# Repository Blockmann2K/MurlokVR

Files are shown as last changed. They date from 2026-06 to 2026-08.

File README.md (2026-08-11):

<div align="center">


# MurlokVR
A Stupid Simple Custom "DIY" VR Headset. Built With Rust 🦀 and C++ (OpenVR Driver) ⚙️

</div>

## Notice
If You Want To Clone This Repository, Use the `--recursive` Flag To Clone the Submodules As Well.

## Overview Architecture
The MurlokVR Headset Follows a Simple Pipeline Approach Which Is Drawn as a Diagram Below:

<div align="center">
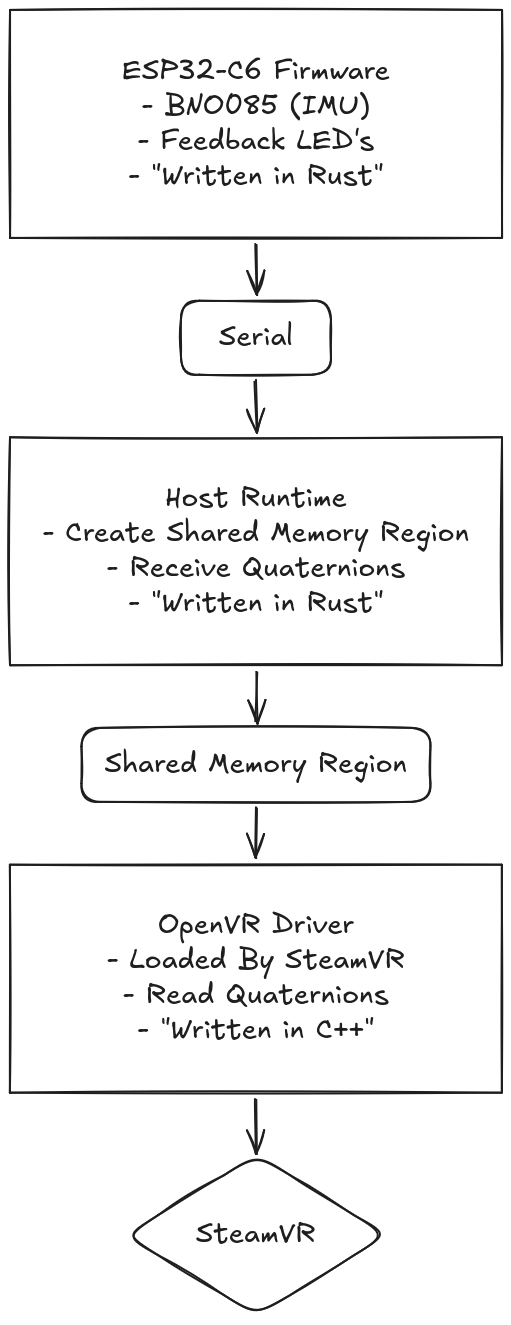
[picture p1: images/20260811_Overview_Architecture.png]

</div>

---

## Overview Components
**Components:**
- Microcontroller:
    - `Waveshare ESP32-C6-(N16) (16 MB Flash Memory)`
- Displays:
    - `Wisecoco 2.9-Inch, 1440 × 1440, 90 Hz, Dual Displays Including Display Driver Board`
- IMU Sensor:
    - `TENSTAR BNO085`
- Lenses:
    - `2x Stacked Fresnel Lenses (2x FL 30 & 2x FL 40)`
        - `Eye <-> FL 40 Lens (Flat Side) <-> FL 30 Lens (Flat Side) <-> Displays`
- LEDs:
    - `1x White LED`
    - `1x RGB LED`
- Resistors:
    - `4x 220 Ω THT`
- Miscellaneous:
    - `HDMI-Cable, USB-Cables, Jumper Wires, ...`

## Headset Design

<div align="center">
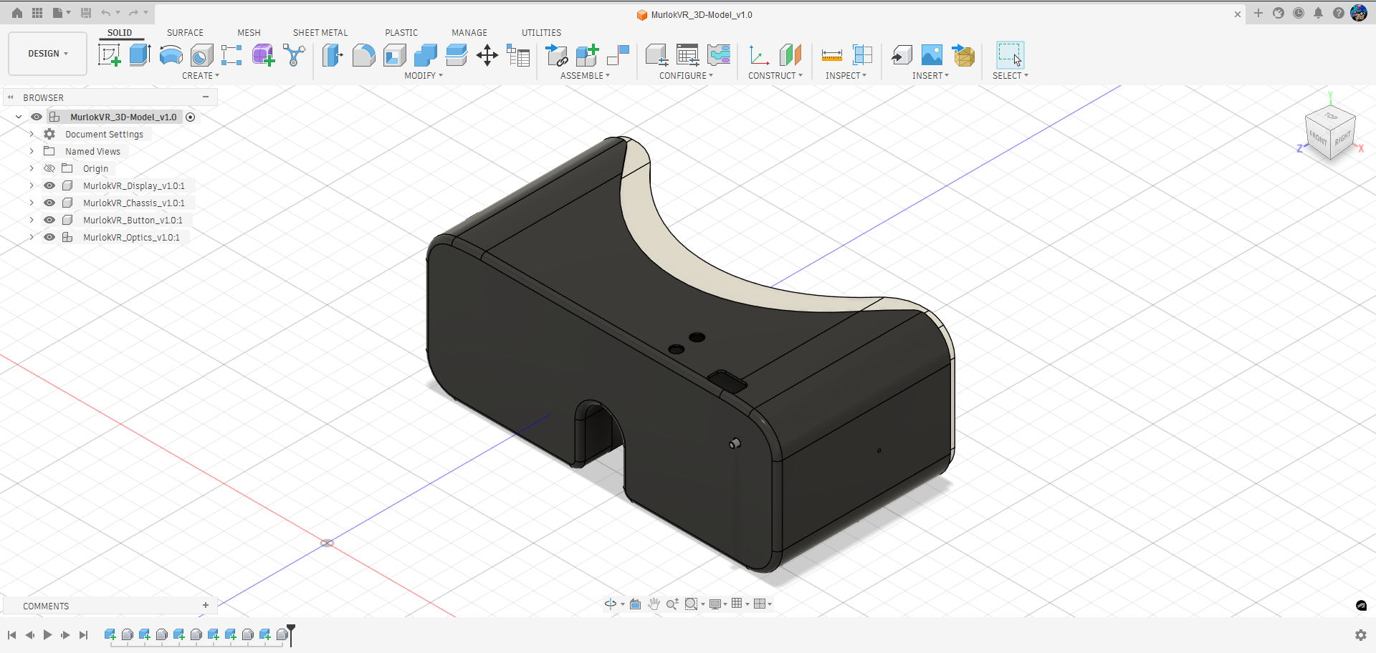
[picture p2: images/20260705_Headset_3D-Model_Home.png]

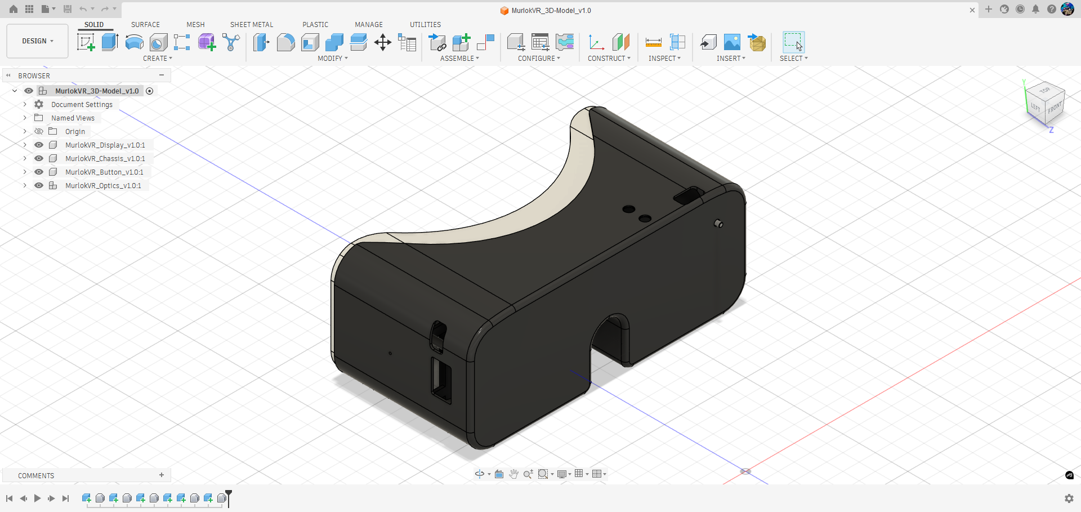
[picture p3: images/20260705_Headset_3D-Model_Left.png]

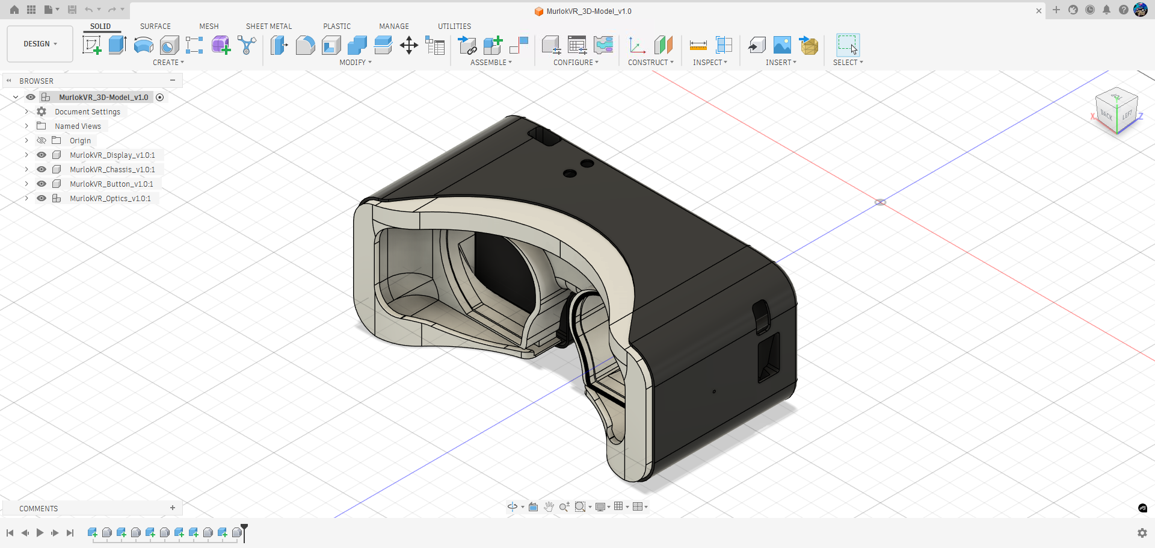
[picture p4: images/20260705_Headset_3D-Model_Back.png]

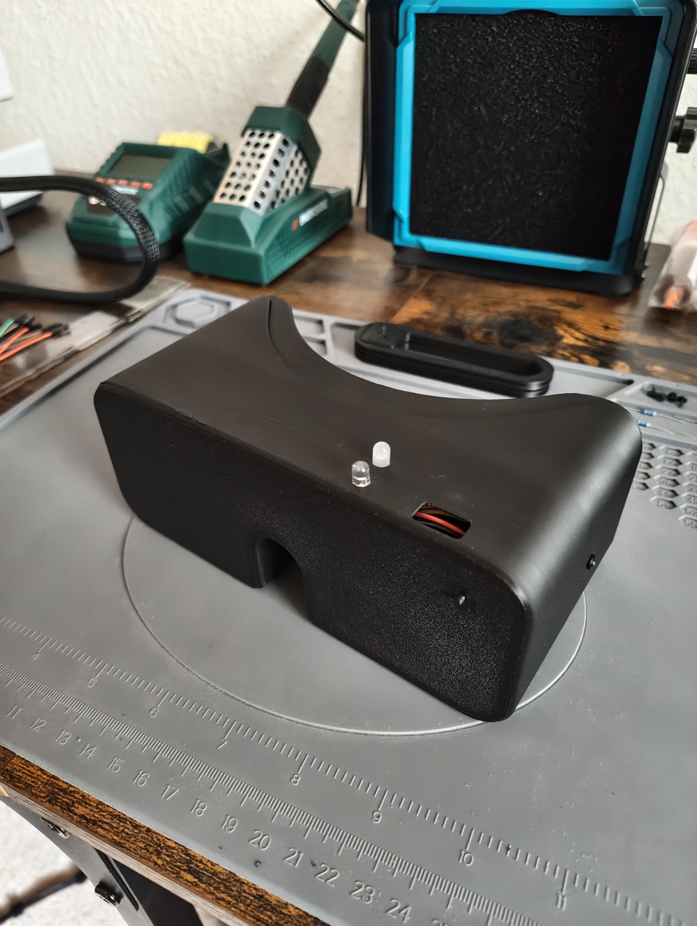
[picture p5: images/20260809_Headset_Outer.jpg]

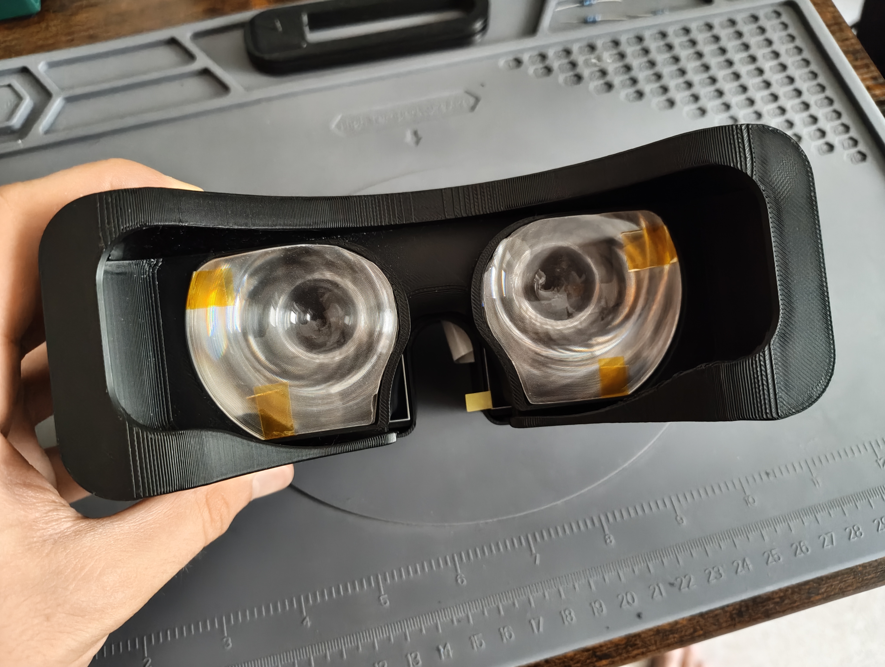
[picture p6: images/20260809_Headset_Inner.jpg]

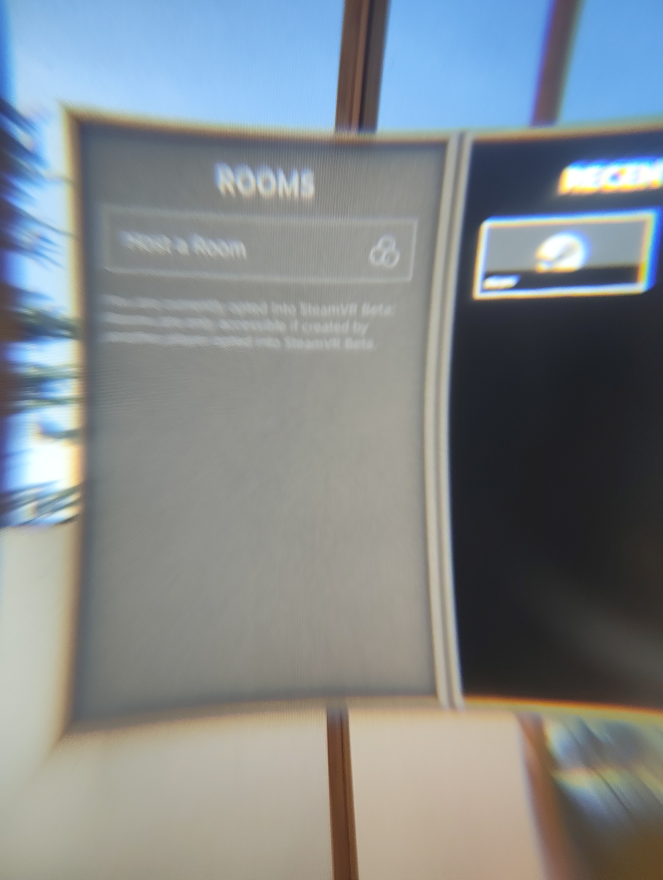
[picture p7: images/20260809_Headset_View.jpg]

</div>

---

## Quick Progress Overview

### Foundation
- [x] Basic Project Structure

### Core Software
- [x] Firmware Implementation in Rust
- [x] Driver Implementation in C++
- [x] Runtime Implementation in Rust
- [x] Driver / Runtime Integration

### Hardware
- [x] Hardware Design

### Testing & Documentation
- [x] Testing
- [x] Documentation

> *More Milestones To Be Added As the Project Evolves...*

## Known Issues
- [ ] Rework Optics System for Easier Assembly ;( and Wider Field of View.

## Known Bugs
- [ ] Fix the Timeout Issue When the Script Didn't Properly Clean Up.
- [ ] Fix the Rotation Issue When the Headset (Firmware) Is Starting in a `Different Position` Than Intended.

## Useful Documentation
```
- Rust – Espressif HAL (Hardware Abstraction Layer):
    - https://github.com/esp-rs/esp-hal
    - https://docs.espressif.com/projects/rust/

- BNO08X Data Sheet:
    - https://www.ceva-ip.com/wp-content/uploads/BNO080_085-Datasheet.pdf

- SH-2 Reference Manual:
    - https://www.ceva-ip.com/wp-content/uploads/SH-2-Reference-Manual.pdf

- Valve Software OpenVR SDK:
    - https://github.com/ValveSoftware/openvr
```

## License
MurlokVR Is Licensed Under **Either** of the Following Licenses, at Your Option:

- [MIT License](LICENSE-MIT)
- [Apache License 2.0](LICENSE-APACHE)

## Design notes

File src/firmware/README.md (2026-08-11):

<div align="center">


# MurlokVR Firmware
This is the MurlokVR Firmware.
</div>

## Overview
The `MurlokVR Firmware` (ESP32-C6 Firmware) Initializes the BNO08X IMU Sensor Over a High-Speed I²C Interface and Continuously Reads Its Orientation Data As Quaternion Values.

The Current Quaternion Is Transmitted Over the Serial Interface in X/Y/Z/W Format for Processing by the MurlokVR Runtime.

The RGB LED Indicates the BNO08X Sensor Status:
- **Green** When New Quaternion Data Is Available and **Orange** When No New Quaternion Data Is Available.
- The White LED Serves as a Power Indicator.

## License
MurlokVR Is Licensed Under **Either** of the Following Licenses, at Your Option:

- [MIT License](LICENSE-MIT)
- [Apache License 2.0](LICENSE-APACHE)

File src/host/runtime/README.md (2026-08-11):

<div align="center">


# MurlokVR Runtime
This is the MurlokVR Runtime.
</div>

## Overview
The `MurlokVR Runtime` Reads Orientation Data From an ESP32-C6 Over a Serial Connection and Makes the Processed VR Headset Pose Available Through Shared Memory.

At Startup, the Runtime Configures the VR Display, Creates a Shared Memory Region for the Headset Pose and Opens the Configured Serial Port.

It Then Continuously Reads Quaternion Data From the ESP32-C6, Parses the Received X/Y/Z/W Quaternion Components and Applies IMU's Mounting and Pose Corrections.

The Corrected Quaternion Is Then Converted to the Coordinate System Expected by OpenVR and Written to the Shared Memory Region. The Pose Data Is Synchronized and Safely Shared With Other Components Through the Shared Memory Region.

## License
MurlokVR Is Licensed Under **Either** of the Following Licenses, at Your Option:

- [MIT License](LICENSE-MIT)
- [Apache License 2.0](LICENSE-APACHE)

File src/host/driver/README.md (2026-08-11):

<div align="center">


# MurlokVR Driver
A Custom OpenVR (SteamVR) Driver for the MurlokVR VR Headset.
</div>

## Overview

This Driver Integrates the MurlokVR Headset Into SteamVR by Implementing the OpenVR Driver Interface. It Was Built on Top of Valve’s Official `simplehmd` Sample Driver as a Starting Point, Extended With Custom Logic To Handle the MurlokVR Hardware.

The Driver Locates and Opens the Shared Memory Region Created by the Rust Runtime, Reads the VR Pose Data Into a Snapshot, and Maps It to the Appropriate Pose Values in `GetPose()`.
This Check Occurs on Every `GetPose()` Call To Handle Cases Where the Rust Runtime May Start Before or After SteamVR Is Already Running.

---

## Folder Structure

```
driver/
├── MurlokVR/
│   ├── bin/
│   │   └── win64/
│   │       └── driver_MurlokVR.dll     # Compiled Driver DLL
│   ├── resources/                      # Driver Resources (Icons, Settings)
│   └── driver.vrdrivermanifest         # SteamVR Driver Manifest
├── src/
│   ├── device_provider.cpp/.h          # Entry Point — Registers the HMD With SteamVR
│   ├── hmd_device_driver.cpp/.h        # Core HMD Logic (Pose, Display, Properties)
|   ├── hmd_driver_factory.cpp          # Driver Factory — Exposes the Driver to OpenVR
|   ├── shared_memory.h                 # Shared Memory — Open Shared Memory & Pose Polling
│   └── vr_pose_shared.h                # VR Pose — VR Pose Shared & VR Pose Snapshot
├── CMakeLists.txt                      # CMake Build Configuration
├── simplehmd.vcxproj                   # Visual Studio Project File
└── README.md
```

---

## Building

It Is Recommended To Build the Driver Using **MSVC** With **CMake**.

---

## Registering

Use `vrpathreg.exe` To Register or Unregister the Driver With SteamVR Without Copying Files Manually.

```powershell
# Navigate to the SteamVR Tools Directory
cd "C:\Program Files (x86)\Steam\steamapps\common\SteamVR\bin\win64"

# Register the Driver
.\vrpathreg.exe adddriver "<path-to-repo>\src\host\driver\MurlokVR"

# Verify Registration
.\vrpathreg.exe show

# Unregister the Driver
.\vrpathreg.exe removedriver "<path-to-repo>\src\host\driver\MurlokVR"
```

Restart SteamVR After Registering for the Driver To Take Effect.

---

## License

This Project Is for Personal and Educational Use. Built on Top of the [OpenVR SDK](https://github.com/ValveSoftware/openvr) Sample Driver (`simplehmd`) by Valve Software.

MurlokVR Is Licensed Under **Either** of the Following Licenses, at Your Option:

- [MIT License](LICENSE-MIT)
- [Apache License 2.0](LICENSE-APACHE)

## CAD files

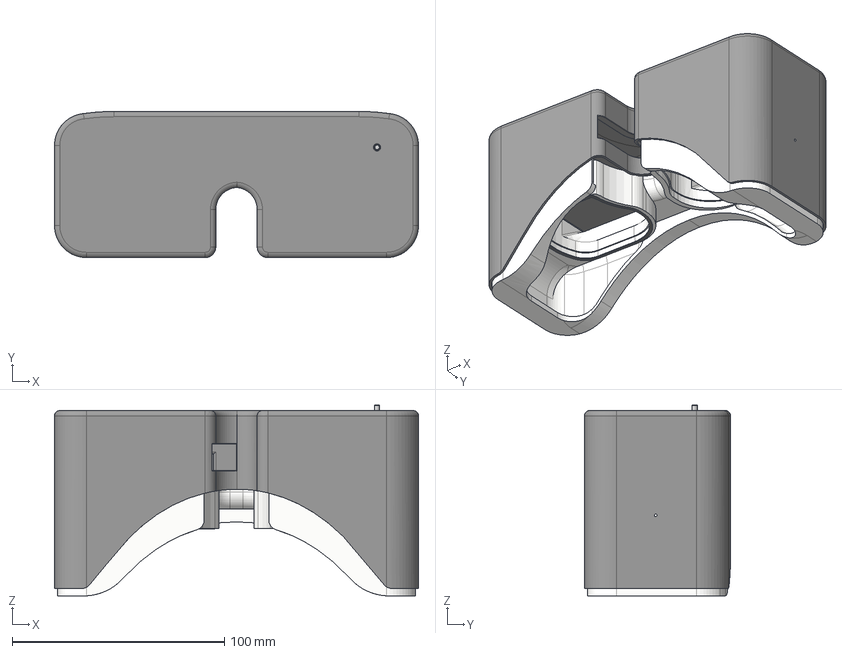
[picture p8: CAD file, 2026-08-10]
hardware/printable/MurlokVR_Complete_v1.0.step
171.5 x 68.9 x 90.0 mm
LCD Holder
Front

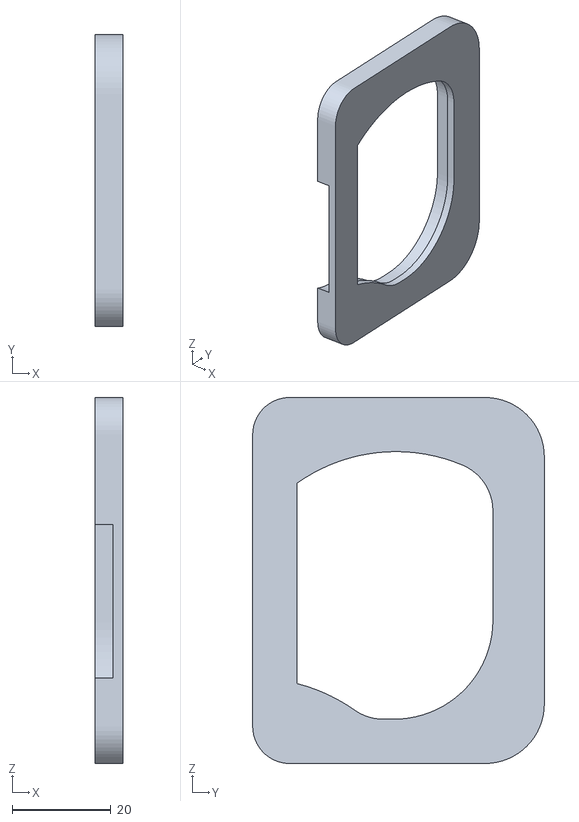
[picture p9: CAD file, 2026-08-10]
hardware/printable/Mañolo_Lens_Cutter_Step_2.stl
5.70 x 59.0 x 74.0

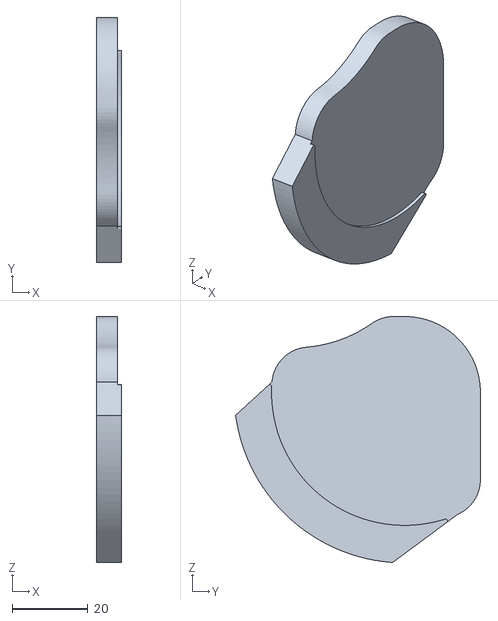
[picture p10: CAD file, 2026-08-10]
hardware/printable/Mañolo_Lens_Cutter_Step_1_B.stl
6.50 x 64.6 x 64.9

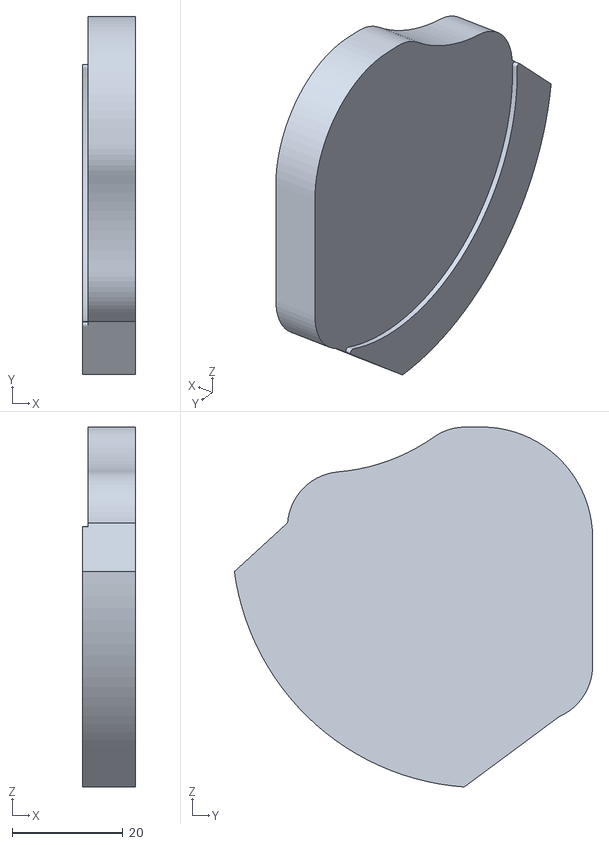
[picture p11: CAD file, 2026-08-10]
hardware/printable/Mañolo_Lens_Cutter_Step_1_A.stl
9.50 x 64.6 x 64.9

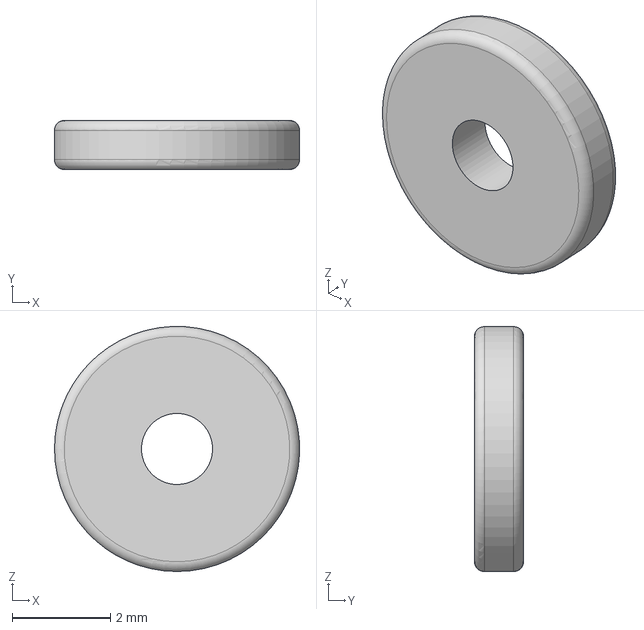
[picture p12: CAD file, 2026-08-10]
hardware/printable/MurlokVR_M1.4_Washers_v1.0.step
5.00 x 1.00 x 5.00 mm

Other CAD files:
hardware/printable/MurlokVR_Complete_v1.0.f3d
hardware/printable/MurlokVR_M1.4_Washers_v1.0.f3d

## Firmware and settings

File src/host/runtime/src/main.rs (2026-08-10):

// Copyright (c) 2026 MurlokVR Contributors
// SPDX-License-Identifier: MIT OR Apache-2.0

/* ! ToDo's:
        - [] Fix the Timeout Issue When the Script Didn't Properly Clean Up.
        - [] Fix the Rotation Issue When the Headset (Firmware) Is Starting in a `Different Position` Than Intended.
*/

//-----------------------------------------------------------------------------
// Dependencies
//-----------------------------------------------------------------------------
// Shared Memory Module
use crate::shared_memory::SharedMemory;

// VR Pose Shared Module
use crate::vr_pose_shared::VRPoseShared;

// VR Display Properties Module
use crate::vr_display_properties::VRDisplayProperties;

// The Rust Standard Library
use std::f32;
use std::io::{self, BufRead, BufReader, Write};
use std::sync::atomic::Ordering;
use std::time::Duration;

// Nalgebra (General-Purpose Maths) Crate
use nalgebra::{Quaternion, UnitQuaternion, Vector3};

// Define Our Shared Memory Module
mod shared_memory;

// Define Our VR Pose Shared Module
mod vr_pose_shared;

// Define Our VR Display Properties Module
mod vr_display_properties;

//-----------------------------------------------------------------------------
// Constants
//-----------------------------------------------------------------------------
const DEFAULT_PORT: &str = "COM4";

fn main() {
    // ==> Header <==
    println!();
    println!("┌─────────────────────────────────────────────┐");
    println!("│            >> MurlokVR Runtime <<           │");
    println!("├─────────────────────────────────────────────┤");
    println!("│ Version  : v{}                           │", env!("CARGO_PKG_VERSION"));
    println!("│ Status   : Experimental                     │");
    println!("│ Target   : ESP32-C6                         │");
    println!("│ Protocol : Serial                           │");
    println!("│ Author   : MurlokVR Contributors            │");
    println!("│                                             │");
    println!("│ Notice   :                                  │");
    println!("│ Ensure VR Display Is 'Landscape (Flipped)'  │");
    println!("│ Ensure VR Display Is 'Primary'              │");
    println!("└─────────────────────────────────────────────┘");
    println!();
    print!("Specify the ESP32 Port (Press Enter for COM4 - Default): ");

    io::stdout().flush().expect("ERROR: Failed To Flush!");

    // ==> Select Port <==
    let mut port_buf = String::new();

    io::stdin().read_line(&mut port_buf).expect("ERROR: Failed To Read Line!");

    let mut port_select = port_buf.trim();

    if port_select.is_empty() {
        port_select = DEFAULT_PORT; // Fall Back to Default Port
    }

    // ==> Configure VR Display Properties <==
    let mut vr_display_properties = VRDisplayProperties::default();

    vr_display_properties.detect_vr_display();

    vr_display_properties.apply_vr_display_properties();

    // ==> Create & Map Shared Memory Region <==
    let mut shared_memory = SharedMemory::<VRPoseShared>::create().unwrap();

    let vr_pose_shared = shared_memory.map_view_as_mut().unwrap();

    // ==> Open Port <==
    let port = serialport::new(port_select, 115_200)
        .timeout(Duration::from_millis(1000))
        .open()
        .expect("ERROR: Failed To Open Port!");

    // ==> Define Pose Orientation Offset <==
    let offset_axis = Vector3::y_axis(); // Rotation Offset Axis (Y)

    let offset_angle = f32::consts::FRAC_PI_2; // 90° Rotation Offset

    let offset_unit_quat = UnitQuaternion::from_axis_angle(&offset_axis, offset_angle);

    // ==> Read, Parse & Send Quaternions <==
    let mut buf = String::new();

    let mut reader = BufReader::new(port);

    loop {
        let _ = reader.read_line(&mut buf);

        let parts: Vec<&str> = buf.split(',').collect();

        if parts.is_empty() {
            break;
        }

        vr_pose_shared.sequence_counter.fetch_add(1, Ordering::Release);

        let quat_x: f32 = match parts[0].trim_start_matches("X:").trim().parse() {
            Ok(value) => value,
            Err(_) => continue,
        };

        let quat_y: f32 = match parts[1].trim_start_matches("Y:").trim().parse() {
            Ok(value) => value,
            Err(_) => continue,
        };

        let quat_z: f32 = match parts[2].trim_start_matches("Z:").trim().parse() {
            Ok(value) => value,
            Err(_) => continue,
        };

        let quat_w: f32 = match parts[3].trim_start_matches("W:").trim().parse() {
            Ok(value) => value,
            Err(_) => continue,
        };

        // Apply IMU's Mounting and Pose Corrections
        let raw_quat = Quaternion::new(quat_w, -quat_x, -quat_y, quat_z); // Compensate for IMU's Mounting Orientation

        let raw_unit_quat = UnitQuaternion::from_quaternion(raw_quat);

        let new_unit_quat = offset_unit_quat * raw_unit_quat; // Apply Pose Orientation Offset

        let new_quat = new_unit_quat.into_inner();

        // Translate From IMU's to OpenVR Axes
        vr_pose_shared.quaternion_x = new_quat.j; // Map Quaternion Y -> X
        vr_pose_shared.quaternion_y = new_quat.i; // Map Quaternion X -> Y
        vr_pose_shared.quaternion_z = new_quat.k;
        vr_pose_shared.quaternion_w = new_quat.w;

        vr_pose_shared.sequence_counter.fetch_add(1, Ordering::Release);

        println!("{:?}", vr_pose_shared);

        buf.clear();
    }
}

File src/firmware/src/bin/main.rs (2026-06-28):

// Copyright (c) 2026 MurlokVR Contributors
// SPDX-License-Identifier: MIT OR Apache-2.0

//-----------------------------------------------------------------------------
// Attributes
//-----------------------------------------------------------------------------
#![no_std] // No Rust Standard Library - Bare-Metal Target
#![no_main] // No Rust Runtime Entry Point - Custom Entry Point via '#[main]'
#![deny(clippy::mem_forget)] // ...
#![deny(clippy::large_stack_frames)] // ...

//-----------------------------------------------------------------------------
// Dependencies
//-----------------------------------------------------------------------------
// BNO08X Module
use crate::bno08x::*;

// RGB LED Module
use crate::rgb_led::*;

// ESP32 Backtrace
use esp_backtrace as _;

// ESP32 Hardware Abstraction Layer
use esp_hal::main;

use esp_hal::clock::CpuClock;
use esp_hal::gpio::{Input, InputConfig, Level, Output, OutputConfig};
use esp_hal::i2c::master::{Config, I2c as I2C, SoftwareTimeout};
use esp_hal::time::{Duration, Rate};

// Logging
use esp_println::println;

// Define Our BNO08X Module
mod bno08x;

// Define Our RGB LED Module
mod rgb_led;

//-----------------------------------------------------------------------------
// App Descriptor
//-----------------------------------------------------------------------------
// Create a Default App-Descriptor Required by the ESP-IDF Bootloader.
esp_bootloader_esp_idf::esp_app_desc!();

//-----------------------------------------------------------------------------
// Entry Point
//-----------------------------------------------------------------------------
#[allow(clippy::large_stack_frames)] // ...
#[main]
fn main() -> ! {
    // Initialize Logger
    esp_println::logger::init_logger_from_env();

    // Configure the CPU To Run at Its Maximum Supported Frequency.
    let config = esp_hal::Config::default().with_cpu_clock(CpuClock::max());

    // Initialize All Peripherals With the Above Config.
    let peripherals = esp_hal::init(config);

    // Power Indicator - White LED
    let _led_white = Output::new(peripherals.GPIO11, Level::High, OutputConfig::default());

    // Status Indicator - RGB LED
    let red = Output::new(peripherals.GPIO10, Level::Low, OutputConfig::default());
    let green = Output::new(peripherals.GPIO1, Level::Low, OutputConfig::default());
    let blue = Output::new(peripherals.GPIO0, Level::Low, OutputConfig::default());

    let mut rgb_led = Led::new(red, green, blue);

    // BNO08X - I2C
    let i2c = I2C::new(
        peripherals.I2C0,
        Config::default()
            .with_frequency(Rate::from_khz(1000)) // Fast-Mode Plus I²C (1000 kHz)
            .with_software_timeout(SoftwareTimeout::PerByte(Duration::from_millis(10))), // Tolerate Brief Clock Stretching
    )
    .expect("ERROR: Failed To Initialize I2C Peripheral!")
    .with_scl(peripherals.GPIO22)
    .with_sda(peripherals.GPIO23);

    // BNO08X - Interrupt
    let int = Input::new(peripherals.GPIO21, InputConfig::default());

    // BNO08X IMU Sensor - Read Quaternions
    let mut bno08x = BNO08X::new(i2c, int, Frequency::Fastest);

    bno08x.drain_advertisement_packets();

    bno08x.set_feature();

    let mut prev_quat = Quaternion::new();

    // Main Loop
    loop {
        let quat = bno08x.get_quaternion();

        match quat {
            Some(curr_quat) => {
                println!(
                    "X:{},Y:{},Z:{},W:{}",
                    curr_quat.x, curr_quat.y, curr_quat.z, curr_quat.w
                );

                if prev_quat == curr_quat {
                    rgb_led.try_set_color(Colors::Yellow);
                } else {
                    rgb_led.try_set_color(Colors::Green);
                }

                prev_quat = curr_quat;
            }

            None => {
                println!(
                    "X:{},Y:{},Z:{},W:{}",
                    prev_quat.x, prev_quat.y, prev_quat.z, prev_quat.w
                );
            }
        }
    }
}

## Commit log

2026-03-22 Initial Commit: MurlokVR DIY VR Headset Project
    Add Complete Project Foundation Including:
    - Rust Workspace With Firmware and Runtime Components
    - OpenVR Driver Implementation for Windows
    - Project Documentation and Architecture Docs
    - Hardware Design and Research Directories
    - Dual Licensing (MIT + Apache 2.0)
    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
2026-03-27 feat(shared-mem): Add Windows API Dependencies to Shared Memory Crate
    - Add `windows-sys` Dependency With Win32_Security and Win32_System_Memory Features
    - Import Windows API Bindings for Memory Management and Foundation Types
    [main.rs]
2026-03-29 feat(shared-mem): Implement Very Simple Shared Memory Module for MurlokVR
    - Replace `main.rs` in `shared-mem` With `lib.rs`
    - Add `SharedMemory` Struct With Windows API Bindings
    - Create Shared Memory Allocation Using `CreateFileMappingW`
    - Add Basic Error Handling for Memory Allocation Failures
    - Integrate `shared-mem` Dependency Into Runtime Module
    This Establishes the Foundation for Inter-Process Communication Between MurlokVR Components Using Windows Shared Memory.
    [main.rs]
2026-04-03 feat(shared-mem): Add Shared Data Module and Initialize in Main
    - Create New `shared_data` Module With Sequence Counter, Device Status, Heartbeat Timestamp and Quaternion Data
    - Initialize Shared Data in `main.rs` With Default Values
    - Add Debug Prints for Shared Data Values
2026-04-07 feat(shared-mem): Rework Shared Memory System
    - Create New Shared Memory Module
    - Implement Shared Memory Safe Trait
    - Refactor Shared Data to VR Pose Shared
    - Update Workspace Configuration
    - Add `rustfmt` Configuration
    - Remove Deprecated `shared-mem` Crate
    [main.rs, mod.rs]
2026-04-07 fix(shared-mem): Correct Unit in Debug Message
    - Change "Bits" to "Bytes" in Debug Message for Clarity
    [mod.rs]
2026-04-10 refactor(shared-mem): Improve Shared Memory Implementation
    - Add Proper Error Handling for Shared Memory Creation
    - Implement Proper Mapping and Unmapping of Memory Views
    - Add Debug Logging for Memory Operations
    - Remove Redundant Validation Function
    - Add Proper Documentation for Memory Address Field
    - Add `PhantomData` Marker for Type Safety
    - Improve Error Handling in `map_view_as_mut`
    - Add Proper Clean Up in Drop Implementation
    - Add Debug Logging for Clean Up Operations
    [main.rs, mod.rs]
2026-04-11 feat(shared-mem): Add Shared Memory Communication Between Host and Driver
    - Add Shared Memory Header Files for VR Pose Data
    - Implement Temporary Test Program To Read Shared Memory
    - Update Rust Runtime To Write VR Pose Data to Shared Memory
    - Add Sequence Counter for Thread-Safe Memory Access
    [_temporary.obj]
2026-04-11 feat(shared-mem): Implement Shared Memory Pose Polling
    - Add Shared Memory Connection and Pose Polling in `hmd_device_driver.cpp`
    - Create `shared_memory.h` With Memory Mapping and Pose Reading Functions
    - Update `vr_pose_shared.h` With `VRPoseShared` and `VRPoseSnapshot` Structs
    - Remove Temporary Test Files (`_temporary.cpp`, `_temporary.exe`, `_temporary.obj`)
    - Modify `main.rs` To Update Quaternion Values for Simple Y (Yaw) Rotating
    [_temporary.obj]
2026-04-14 chore(firmware): Update Build Script and Add `rustfmt` Configuration
    - Improve Error Messages in `linker_be_nice` Function
    - Add `rustfmt` Configuration File With `max_width = 160`
    - Update `rust-toolchain.toml` Comment To Specify ESP32-C6 Target
2026-05-02 chore(firmware): Update Dependencies to Latest Versions
    - Update `esp-hal` to v1.1.0
    - Update `esp-bootloader-esp-idf` to v0.5.0
    - Update `log` to v0.4.0
    - Update `esp-backtrace` to v0.19.0
    - Update `esp-println` to v0.17.0
2026-05-02 feat(firmware): Update `rustfmt` `max_width` & Add SPI Initialization
    - Reduce `rustfmt` `max_width` From 160 to 140
    - Add SPI Initialization for BNO085 Sensor
    - Add Example SPI Transfer and Logging
2026-05-10 feat(firmware): Add BNO08X Sensor Module
    - Create New BNO08X Module With SPI and Interrupt Pin
    - Implement Ready Check Functionality
    - Add BNO08X Initialization in `main`
    - Update `main` Loop To Use BNO08X Module
2026-05-10 chore(firmware): Remove BNO08X Module and Related Code
    - Remove BNO08X Struct and Implementation
    - Remove SPI and GPIO Initialization Code
    - Remove BNO08X Usage in `main` Loop
    - Update `main` Loop To Print "Hello, MurlokVR!"
2026-05-10 feat(firmware): Add Constants Module
    - Add BNO08X I2C Address Constant
    - Add SHTP Channel Numbers Constants
    - Add SH-2 Report IDs Constants
    - Add Report Interval Constants
    - Add Q14 Fixed-Point Scale Factor Constant
    [mod.rs]
2026-05-16 feat(firmware): Implement BNO08X Sensor Integration
    - Add BNO08X Module With Constants, Structs, and Implementations
    - Implement Quaternion Data Structure and Validation
    - Add I2C Initialization and Configuration
    - Implement Sensor Initialization, Packet Draining, and Feature Setting
    - Add Main Loop for Reading and Logging Quaternion Data
    - Remove `rustfmt.toml` File
    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
2026-05-17 refactor(firmware): Make Quaternion Fields Public and Update Logging
    - Make Quaternion Struct Fields Public
    - Replace `log::info` With `esp_println::println`
    - Update Quaternion Logging Format
    [main.rs, mod.rs]
2026-05-20 chore(firmware): Update Logging To Use `defmt` & `rtt`
    - Update `Cargo.toml` To Use `defmt` Instead of `log` and `esp-println`
    - Add `defmt` and `rtt-target` Dependencies
    - Replace `log` and `esp-println` Imports With `defmt` Imports
    - Update `build.rs` To Include `defmt.x` Linker Script
    - Add `panic-rtt-target` Dependency for Panic Handling
    - Update BNO08X Module To Use `defmt` Instead of `log`
    - Update `main.rs` To Initialize RTT for `defmt` and Remove `esp_println` Initialization
    [main.rs, mod.rs]
2026-05-22 feat(firmware): Add Interrupt-Driven Quaternion Reporting
    - Add Interrupt Pin to `BNO08X` Struct
    - Implement `Frequency` Enum for Report Rates
    - Add Interrupt Check Before Reading Quaternion
    - Add Channel and Report ID Validation
    - Add Previous Quaternion Storage for When Interrupt Is Inactive
    - Update Report Intervals To Use `Frequency` Enum
    - Add Error Handling for I2C Write Operation
    - Add `new()` Constructor for `Quaternion` Struct
    [main.rs, mod.rs]
2026-05-23 feat(firmware): Add Power Indicator LED
    - Import Necessary GPIO Modules
    - Initialize White LED on GPIO11
    - Set Initial Level to High
2026-05-24 feat(firmware): Add RGB LED Module
    - Add RGB LED Module With Color Control
    - Implement Cooldown To Prevent Rapid Color Changes
    - Add Power Indicator (White LED)
    - Add Status Indicator (RGB LED)
    - Update BNO08X I2C Configuration to Fast-Mode Plus (1000 kHz)
    - Add Quaternion Comparison To Indicate Sensor Status
    - Remove Unused Frequency Variants (Default, Fast)
    [main.rs, mod.rs]
2026-06-28 chore(firmware): Revert `defmt` & `rtt`
    - Add License Headers
    [main.rs, mod.rs]
2026-06-28 feat(runtime): Add Error Handling for Quaternion Parsing
    - Replace Direct Unwraps With Pattern Matching
    - Skip Iteration if Any Quaternion Component Fails To Parse
    - Maintain Existing Quaternion Assignment Logic
    [main.rs]
2026-08-03 feat(runtime): Add `Nalgebra` for Quaternion Math & IMU Orientation Compensation
    - Add `Nalgebra` Dependency
    - Update Quaternion Parsing and Transformation Logic
    - Add Rotation Offset for IMU Orientation Compensation
    - Map Quaternion Axes To Match Physical Mounting
2026-08-05 feat(runtime): Revert Primary Display Check & Improve IMU's Mounting and Pose Corrections
    - Update Default Display Settings in `default.vrsettings`
    - Add Primary Display Check in `vr_display_properties.rs`
    - Remove Unused Imports in `shared_memory.rs`
    - Update Comments and ToDo's in `main.rs` and `vr_display_properties.rs`
    [main.rs, mod.rs]
2026-08-10 docs: Update README, Add 3D-Models & Add Pictures + Videos
    - Update Project Description To Reflect Current Status
    - Add Known Bugs Section
    - Rename Video
    - Add Headset View Video
    - Remove Architecture Documentation
    - Remove Git Reference
    - Remove Wrapper Cheatsheet
    - Add Lens Cutter STL Files
    - Add Headset F3D and STEP Files
    - Add M1.4 Washers F3D and STEP Files
    - Add 3D-Model Pictures
    - Add Headset Pictures
    - Remove Research Folder With Its Content
    - Add Rotation Issue to Runtime ToDo's
    [Mañolo_Lens_Cutter_Step_1_A.stl, Mañolo_Lens_Cutter_Step_1_B.stl, Mañolo_Lens_Cutter_Step_2.stl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]
2026-08-11 docs: Add Known Issues Section and Add Architecture Diagram
    - Add Known Issues Section to README
    - Add New Architecture Diagram
    - Add Firmware README
    - Add Runtime README
    - Update Driver README
2026-08-11 docs: Update Documentation and Add License Information
    - Update README With Improved Formatting and Additional Documentation
    - Add Detailed Overview to Firmware/README
    - Add Detailed Overview to Runtime/README
    - Add License Information to Firmware/README
    - Add License Information to Runtime/README
    - Add License Information to Driver/README
